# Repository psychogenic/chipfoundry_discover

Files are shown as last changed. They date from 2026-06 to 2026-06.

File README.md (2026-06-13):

# ChipFoundry ChipDiscover 2.0

ChipDiscover 2.0 is a mainboard designed to accept a variety of breakout modules (FPGA, TinyTapeout, Chipfoundry ASICs...) via an M.2 interface.

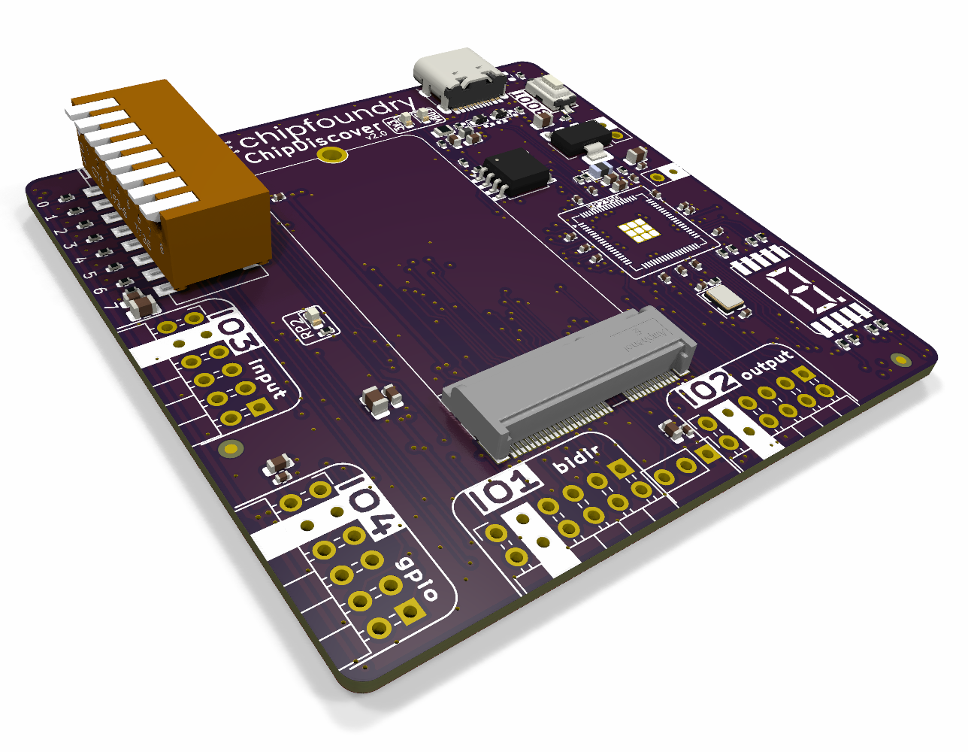
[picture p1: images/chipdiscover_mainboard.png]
Mainboard PCB


## FPGA M.2

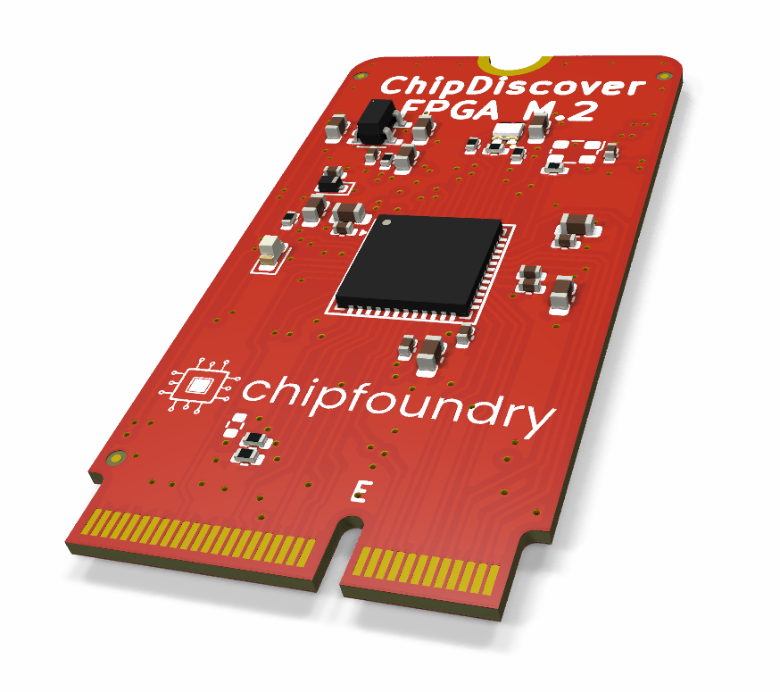
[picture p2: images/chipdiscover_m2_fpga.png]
FPGA PCB


The FPGA M.2 may be used along with [riffpga](https://github.com/psychogenic/riffpga) installed on the mainboard to allow for drag&drop bitstream loading through the USB-C connector and virtual drive.

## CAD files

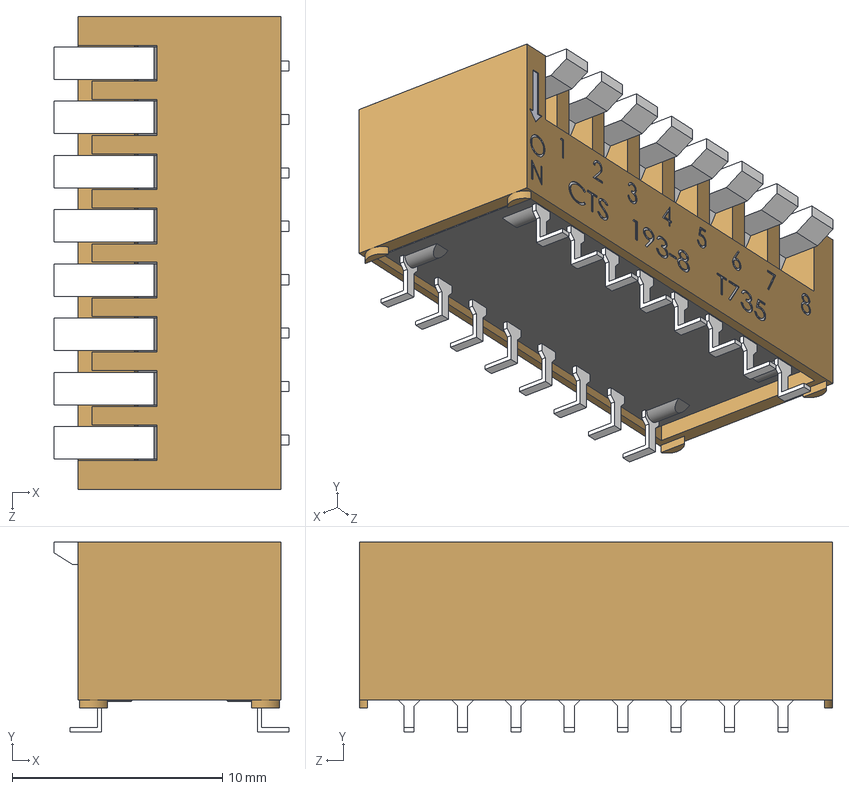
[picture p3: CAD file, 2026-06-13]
models/8bitPianoDIP-193-8MS.STEP
11.2 x 9.02 x 22.5 mm
193-8 pole assembly

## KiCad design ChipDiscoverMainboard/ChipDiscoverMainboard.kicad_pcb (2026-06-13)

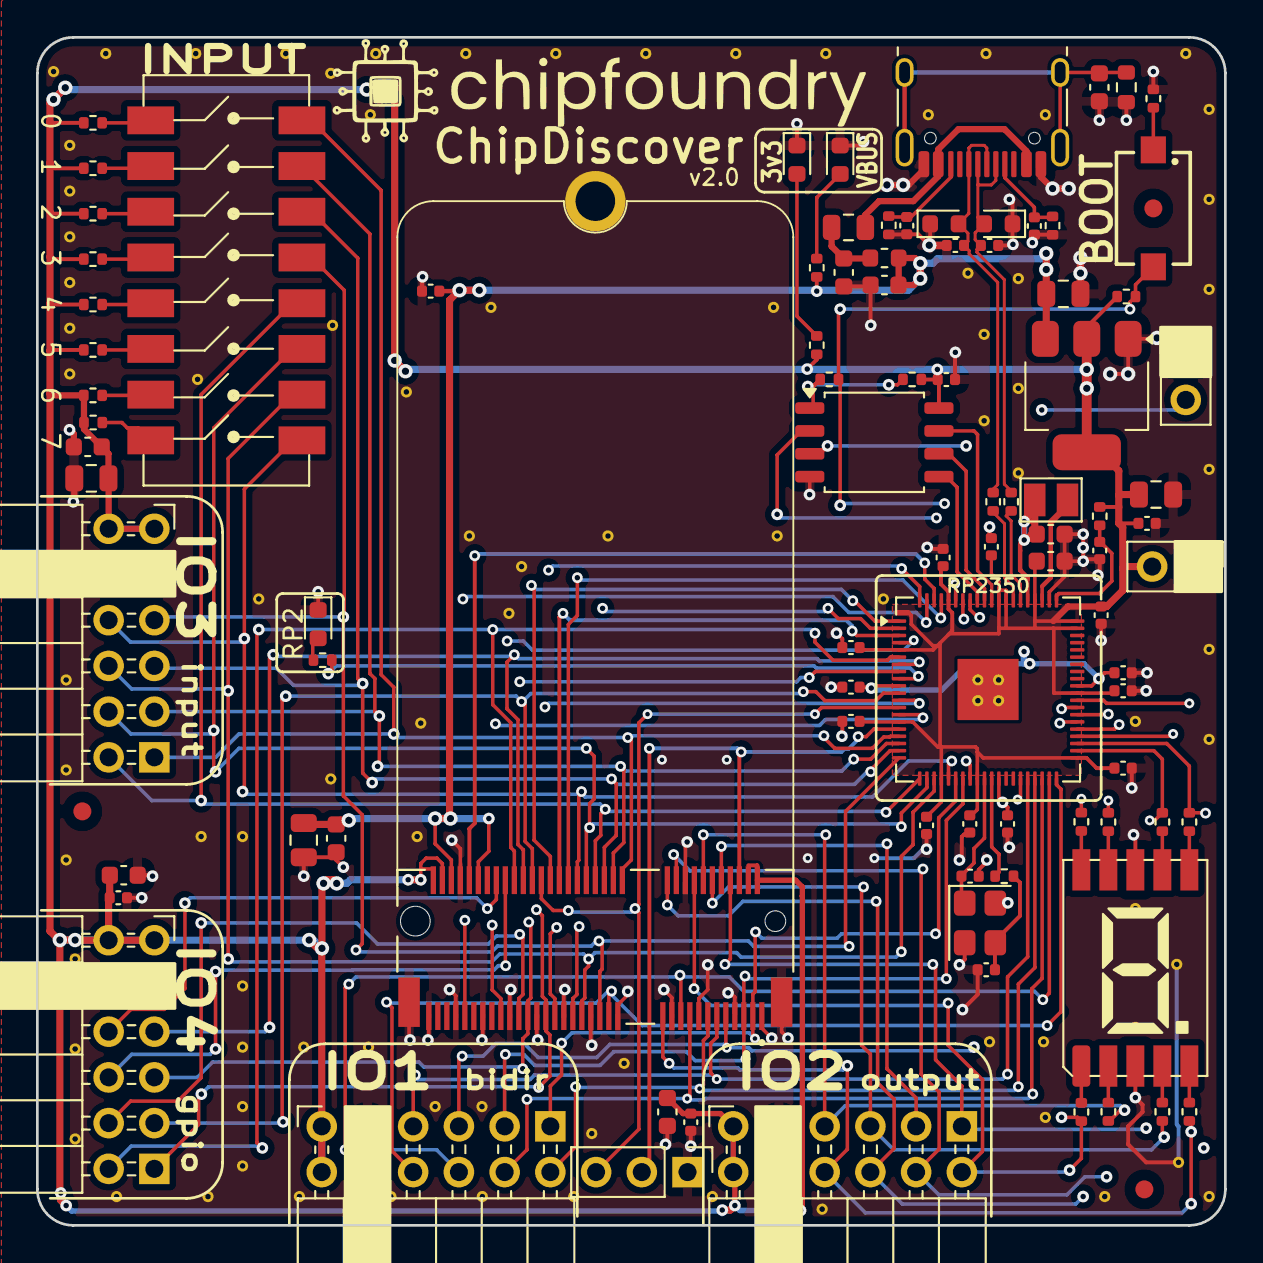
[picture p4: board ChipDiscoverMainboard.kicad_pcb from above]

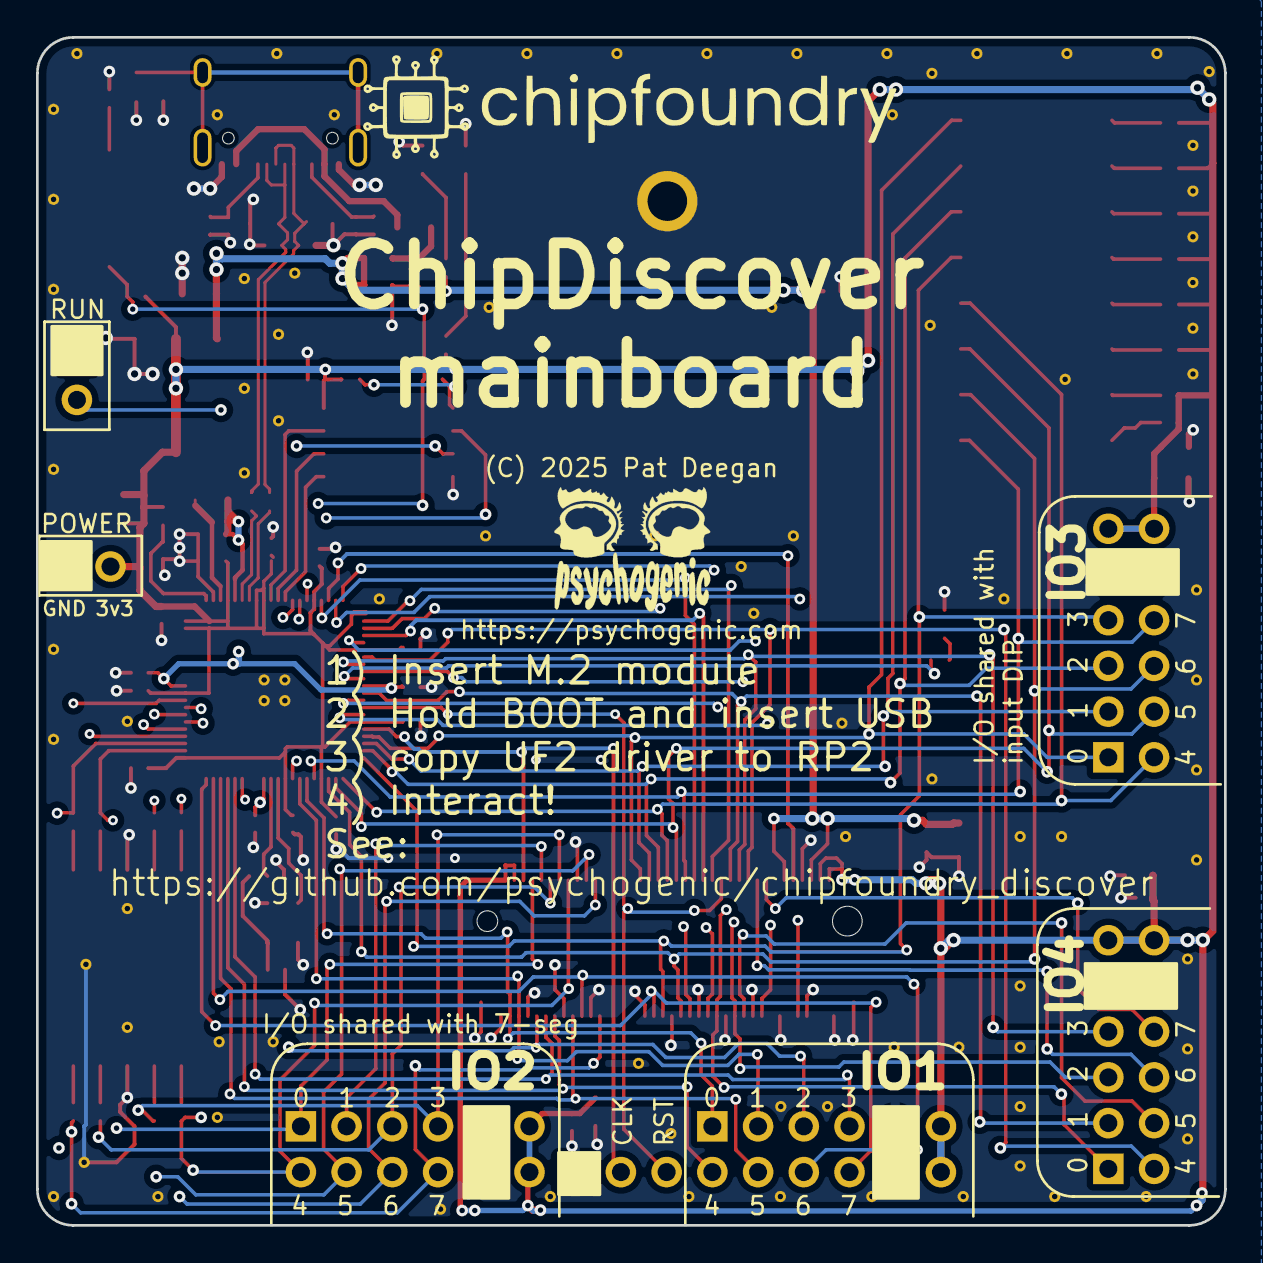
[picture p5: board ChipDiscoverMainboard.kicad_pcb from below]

Board: 4 copper layers, 66.0 x 66.0 mm, 188 parts (2 on the bottom side), 89 nets.

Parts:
C1, C2, C11, C13, C47, C49: 1uF; C_0603_1608Metric
C3, C10, C12: 10uF; C_0805_2012Metric
C4: 22uF; C_0805_2012Metric
C5, C14, C17, C19, C21, C22, C23, C24, C25, C26, C27, C28, C29, C30, C46, C48: 100n; C_0402_1005Metric
C6, C7, C8, C9: 33pF; C_0402_1005Metric
C15: 6800pF; C_0603_1608Metric
C16, C18: 14pF; C_0402_1005Metric
C20, C31: 4.7u; C_0402_1005Metric
C32, C33: 4.7u; C_0603_1608Metric
CHIPFNDRLOGO_LRG: LOGO; chipfoundry_logo_30mm
CHIPFNDRLOGO_LRG#2: LOGO; chipfoundry_logo_30mm
D1, D2: TVS; D_0603_1608Metric
D3, D6, D7: Yellow; LED_0603_1608Metric
F1: 350mA; Fuse_0805_2012Metric
FB1: 120R; L_0603_1608Metric
FID1, FID2, FID3: Fiducial; Fiducial_1mm_Mask2mm
J1: USB_C; USB_C_Receptacle_HRO_TYPE-C-31-M-12
J2, J9: Conn_01x02; PinHeader_1x02_P2.54mm_Vertical
J3: MDT320E01001; AMPHENOL_MDT320E01001
J4: M2SecuringHole; 2242-key-E_footprint
J6, J7, J18, J19: 613012243121; PinSocket_2x06_P2.54mm_PMODHost1A
J8: Conn_01x03; PinHeader_1x03_P2.54mm_Vertical
L1: 3.3u; L_2016X120N
PSYLOGO01: PSYLOGO; PsychoLogoSmall
R1, R2: 5.1k; R_0402_1005Metric
R3: 1M; R_0603_1608Metric
R4, R9: 10k; R_0402_1005Metric
R5, R10, R64, R65, R66, R67, R68, R69, R70, R71: 1k; R_0402_1005Metric
R6, R73, R74, R75, R76, R77, R78, R79, R80, R81: 510; R_0402_1005Metric
R7, R8: 27; R_0402_1005Metric
R11: 0; R_0402_1005Metric
R12: 33R; R_0402_1005Metric
R72: 1.2K; R_0402_1005Metric
STITCH01, STITCH01#2, STITCH01#3, STITCH01#4, STITCH01#5, STITCH01#6, STITCH01#7, STITCH01#8, STITCH01#9, STITCH01#10, STITCH01#11, STITCH01#12, STITCH01#13, STITCH01#14, STITCH01#15, STITCH01#16, STITCH01#17, STITCH01#18, STITCH01#19, STITCH01#20, STITCH01#21, STITCH01#22, STITCH01#23, STITCH01#24, STITCH01#25, STITCH01#26, STITCH01#27, STITCH01#28, STITCH01#29, STITCH01#30, STITCH01#31, STITCH01#32, STITCH01#33, STITCH01#34, STITCH01#35, STITCH01#36, STITCH01#37, STITCH01#38, STITCH01#39, STITCH01#40, STITCH01#41, STITCH01#42, STITCH01#43, STITCH01#44, STITCH01#45, STITCH01#46, STITCH01#47, STITCH01#48, STITCH01#49, STITCH01#50, STITCH01#51, STITCH2, STITCH3, STITCH4, STITCH5, STITCH6, STITCH7, STITCH8, STITCH9, STITCH10, STITCH10#2, STITCH11, STITCH12, STITCH13, STITCH14, STITCH16, STITCH17, STITCH18, STITCH19, STITCH21, STITCH22, STITCH22#2, STITCH23, STITCH24, STITCH25, STITCH26, STITCH26#2, STITCH27, STITCH28, STITCH29, STITCH30, STITCH31, STITCH32, STITCH33, STITCH34, STITCH35, STITCH36, STITCH37, STITCH38, STITCH39: StitchingVia-0.3mm
SW1: 434121025816
SW5: 193-8MSR; GENERIC_PIANO_8DIP
U1: TLV1117LV33; SOT-223-3_TabPin2
U2: RP2350-QFN80; QFN-80-1EP_10x10mm_P0.4mm_EP3.4x3.4mm
U3: W25Q32JVSS; SOIC-8_5.3x5.3mm_P1.27mm
U5: 157112V12700; WL_S7DS-157112V12700
Y1: 12.0MHz; Crystal_SMD_3225-4Pin_3.2x2.5mm

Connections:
+1V1: C19.1, C20.1, C21.1, C33.1, L1.1, U2.10 (DVDD), U2.32 (DVDD), U2.51 (DVDD), U2.65 (VREG_FB)
+3V3: C4.1, C5.1, C10.2, C11.2, C17.1, C22.1, C23.1, C24.1, C25.1, C26.1, C27.1, C28.1, C29.1, C30.1, C32.1, C46.1, C47.2, C48.1, C49.2, J3.2, J3.4, J3.72, J3.74, J6.6 (VCC), J6.12 (VCC), J7.6 (VCC), J7.12 (VCC), J9.2, J18.6 (VCC), J18.12 (VCC), J19.6 (VCC), J19.12 (VCC), R4.1, R9.1, R12.1, R64.1, R65.1, R66.1, R67.1, R68.1, R69.1, R70.1, R71.1, R73.1, U1.2 (VO), U2.5 (IOVDD), U2.15 (IOVDD), U2.24 (IOVDD), U2.29 (IOVDD), U2.41 (IOVDD), U2.50 (IOVDD), U2.59 (ADC_AVDD), U2.60 (IOVDD), U2.64 (VREG_VIN), U2.68 (USB_OTP_VDD), U2.69 (QSPI_IOVDD), U2.76 (IOVDD), U3.8 (VCC)
/BOOT: R4.2, R11.1, SW1.2, U2.75 (QSPI_SS)
/CC1: C6.1, J1.A5 (CC1), R2.1
/CC2: C7.1, J1.B5 (CC2), R1.1
/MSPI.MISO: J3.48, U2.1 (GPIO4)
/MSPI.MOSI: J3.47, U2.80 (GPIO3)
/MSPI.SCK: J3.46, U2.3 (GPIO6)
/MSPI.~SS: J3.43, U2.2 (GPIO5)
/RP2350/CLKIN: C16.1, U2.30 (XIN), Y1.1
/RP2350/CLKO2: C18.1, R10.2, Y1.3
/RP2350/CLKOUT: R10.1, U2.31 (XOUT)
/RP2350/FLASH_SS: R9.2, R11.2, U3.1 (~CS)
/RP2350/QSPI_SCK: U2.71 (QSPI_SCLK), U3.6 (CLK)
/RP2350/QSPI_SD0: U2.72 (QSPI_SD0), U3.5 (DI(IO0))
/RP2350/QSPI_SD1: U2.74 (QSPI_SD1), U3.2 (DO(IO1))
/RP2350/QSPI_SD2: U2.73 (QSPI_SD2), U3.3 (IO2)
/RP2350/QSPI_SD3: U2.70 (QSPI_SD3), U3.7 (IO3)
/RP2350/USBPi_+: R7.2, U2.67 (USB_DP)
/RP2350/USBPi_-: R8.2, U2.66 (USB_DM)
/RP2350/VREG_AVDD: C31.1, R12.2, U2.61 (VREG_AVDD)
/RP2350/VREG_LX: L1.2, U2.63 (VREG_LX)
/RPLED: R6.1, U2.9 (GPIO11)
/RUN: J2.2, U2.35 (RUN)
/chip_rst: J3.59, U2.14 (GPIO15)
/ctrl_ena: J3.44, U2.77 (GPIO0)
/ctrl_sel_inc: J3.67, U2.79 (GPIO2)
/gp0: J3.49, J7.1 (IO1), U2.12 (GPIO13)
/gp1: J3.52, J7.2 (IO2), U2.11 (GPIO12)
/gp2: J3.53, J7.3 (IO3), U2.8 (GPIO10)
/gp3: J3.54, J7.4 (IO4), U2.7 (GPIO9)
/gp4: J3.56, J7.7 (IO5), U2.6 (GPIO8)
/gp5: J3.55, J7.8 (IO6), U2.4 (GPIO7)
/gp6: J3.58, J7.9 (IO7)
/gp7: J3.60, J7.10 (IO8)
/prj_clk: J3.6, J8.2, U2.16 (GPIO16)
/prj_~rst: J3.50, J8.3, U2.13 (GPIO14)
/ui_in0: J3.32, J6.1 (IO1), SW5.16, U2.17 (GPIO17)
/ui_in1: J3.34, J6.2 (IO2), SW5.15, U2.18 (GPIO18)
/ui_in2: J3.36, J6.3 (IO3), SW5.14, U2.19 (GPIO19)
/ui_in3: J3.37, J6.4 (IO4), SW5.13, U2.20 (GPIO20)
/ui_in4: J3.38, J6.7 (IO5), SW5.12, U2.21 (GPIO21)
/ui_in5: J3.40, J6.8 (IO6), SW5.11, U2.22 (GPIO22)
/ui_in6: J3.41, J6.9 (IO7), SW5.10, U2.23 (GPIO23)
/ui_in7: J3.42, J6.10 (IO8), SW5.9, U2.25 (GPIO24)
/uio0: J3.3, J18.1 (IO1), U2.26 (GPIO25)
/uio1: J3.5, J18.2 (IO2), U2.27 (GPIO26)
/uio2: J3.9, J18.3 (IO3), U2.28 (GPIO27)
/uio3: J3.11, J18.4 (IO4), U2.36 (GPIO28)
/uio4: J3.13, J18.7 (IO5), U2.37 (GPIO29)
/uio5: J3.17, J18.8 (IO6), U2.38 (GPIO30)
/uio6: J3.19, J18.9 (IO7), U2.39 (GPIO31)
/uio7: J3.35, J18.10 (IO8), U2.40 (GPIO32)
/uo_out0: J3.8, J19.1 (IO1), R74.1, U2.42 (GPIO33)
/uo_out1: J3.10, J19.2 (IO2), R75.1, U2.43 (GPIO34)
/uo_out2: J3.12, J19.3 (IO3), R76.1, U2.44 (GPIO35)
/uo_out3: J3.14, J19.4 (IO4), R77.1, U2.45 (GPIO36)
/uo_out4: J3.16, J19.7 (IO5), R78.1, U2.46 (GPIO37)
/uo_out5: J3.20, J19.8 (IO6), R79.1, U2.47 (GPIO38)
/uo_out6: J3.22, J19.9 (IO7), R80.1, U2.48 (GPIO39)
/uo_out7: J3.23, J19.10 (IO8), R81.1, U2.49 (GPIO40_ADC0)
/vfused: C1.1, F1.2, FB1.1
/~ctrl_sel_rst: J3.66, U2.78 (GPIO1)
GND: C1.2, C2.2, C3.2, C4.2, C5.2, C6.2, C7.2, C8.2, C9.2, C10.1, C11.1, C12.1, C13.1, C14.1, C15.2, C16.2, C17.2, C18.2, C19.2, C20.2, C21.2, C22.2, C23.2, C24.2, C25.2, C26.2, C27.2, C28.2, C29.2, C30.2, C31.2, C32.2, C33.2, C46.2, C47.1, C48.2, C49.1, D1.1 (A1), D2.1 (A1), D3.1 (K), D6.1 (K), D7.1 (K), J1.A1 (GND), J1.A12 (GND), J1.B1 (GND), J1.B12 (GND), J2.1, J3.1, J3.7, J3.15, J3.18, J3.21, J3.33, J3.39, J3.45, J3.51, J3.57, J3.63, J3.68, J3.69, J3.75, J3.S1 (SHIELD), J3.S2 (SHIELD), J4.1, J6.5 (GND), J6.11 (GND), J7.5 (GND), J7.11 (GND), J8.1, J9.1, J18.5 (GND), J18.11 (GND), J19.5 (GND), J19.11 (GND), R1.2, R2.2, R3.2, R5.2, STITCH01.1, STITCH01#2.1, STITCH01#3.1, STITCH01#4.1, STITCH01#5.1, STITCH01#6.1, STITCH01#7.1, STITCH01#8.1, STITCH01#9.1, STITCH01#10.1, STITCH01#11.1, STITCH01#12.1, STITCH01#13.1, STITCH01#14.1, STITCH01#15.1, STITCH01#16.1, STITCH01#17.1, STITCH01#18.1, STITCH01#19.1, STITCH01#20.1, STITCH01#21.1, STITCH01#22.1, STITCH01#23.1, STITCH01#24.1, STITCH01#25.1, STITCH01#26.1, STITCH01#27.1, STITCH01#28.1, STITCH01#29.1, STITCH01#30.1, STITCH01#31.1, STITCH01#32.1, STITCH01#33.1, STITCH01#34.1, STITCH01#35.1, STITCH01#36.1, STITCH01#37.1, STITCH01#38.1, STITCH01#39.1, STITCH01#40.1, STITCH01#41.1, STITCH01#42.1, STITCH01#43.1, STITCH01#44.1, STITCH01#45.1, STITCH01#46.1, STITCH01#47.1, STITCH01#48.1, STITCH01#49.1, STITCH01#50.1, STITCH01#51.1, STITCH2.1, STITCH3.1, STITCH4.1, STITCH5.1, STITCH6.1, STITCH7.1, STITCH8.1, STITCH9.1, STITCH10.1, STITCH10#2.1, STITCH11.1, STITCH12.1, STITCH13.1, STITCH14.1, STITCH16.1, STITCH17.1, STITCH18.1, STITCH19.1, STITCH21.1, STITCH22.1, STITCH22#2.1, STITCH23.1, STITCH24.1, STITCH25.1, STITCH26.1, STITCH26#2.1, STITCH27.1, STITCH28.1, STITCH29.1, STITCH30.1, STITCH31.1, STITCH32.1, STITCH33.1, STITCH34.1, STITCH35.1, STITCH36.1, STITCH37.1, STITCH38.1, STITCH39.1, U1.1 (GND), U2.62 (VREG_PGND), U2.81 (GND), U3.4 (GND), U5.3 (CC), U5.8 (CC), Y1.2, Y1.4
unnamed: D3.2 (A), R6.2
unnamed: D6.2 (A), R72.2
unnamed: D7.2 (A), R73.2
unnamed: C15.1, J1.S1 (SHIELD), R3.1
unnamed: R5.1, SW1.1
unnamed: R64.2, SW5.1
unnamed: R65.2, SW5.2
unnamed: R66.2, SW5.3
unnamed: R67.2, SW5.4
unnamed: R68.2, SW5.5
unnamed: R69.2, SW5.6
unnamed: R70.2, SW5.7
unnamed: R71.2, SW5.8
unnamed: R74.2, U5.7 (A)
unnamed: R75.2, U5.6 (B)
unnamed: R76.2, U5.4 (C)
unnamed: R77.2, U5.2 (D)
unnamed: R81.2, U5.5 (DP)
unnamed: R78.2, U5.1 (E)
unnamed: R79.2, U5.9 (F)
unnamed: R80.2, U5.10 (G)
VBUS: C2.1, C3.1, C12.2, C13.2, C14.2, FB1.2, J3.64, J3.70, R72.1, U1.3 (VI)
VBUSRW: F1.1, J1.A4 (VBUS), J1.A9 (VBUS), J1.B4 (VBUS), J1.B9 (VBUS)
usb_d+: C9.1, D2.2 (A2), J1.A6 (D+), J1.B6 (D+), R7.1
usb_d-: C8.1, D1.2 (A2), J1.A7 (D-), J1.B7 (D-), R8.1

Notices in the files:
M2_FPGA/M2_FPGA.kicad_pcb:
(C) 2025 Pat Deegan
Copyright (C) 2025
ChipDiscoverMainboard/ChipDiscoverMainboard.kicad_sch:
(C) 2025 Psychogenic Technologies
